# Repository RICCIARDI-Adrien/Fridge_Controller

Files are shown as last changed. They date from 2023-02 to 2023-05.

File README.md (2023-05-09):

# Fridge controller

A very simple controller with a light electronic BoM. It manages the fridge temperature with hardcoded thresholds and hysteresis.

## Project information

The board is powered by a PIC12F683 MCU. It samples the fridge or freezer temperature through a NTC sensor. It then controls the fridge cold unit through a 230V/12A relay.

### Hardware

The board schematic and PCB are designed with KiCad 6.

### Firmware

The microcontroller firmware is compiled with the free version of Microchip XC8 compiler.

## Photo gallery

Naked PCB :
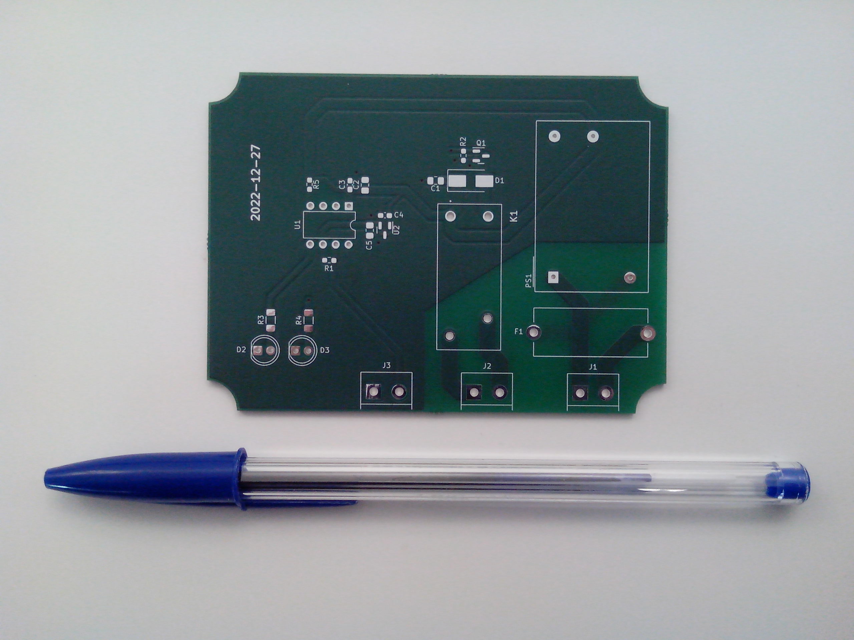
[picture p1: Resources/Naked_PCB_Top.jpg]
Naked PCB top

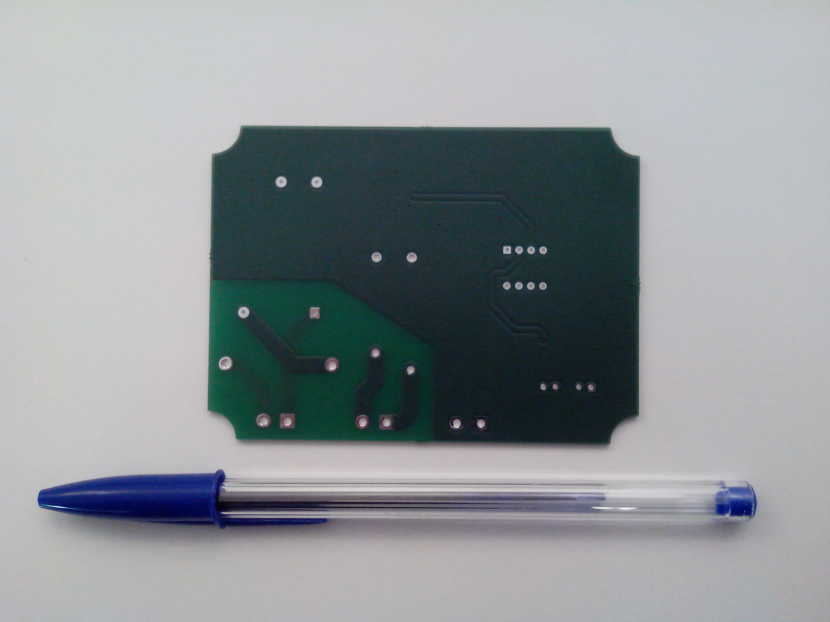
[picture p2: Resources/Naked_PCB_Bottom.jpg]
Naked PCB bottom


Assembled PCB :
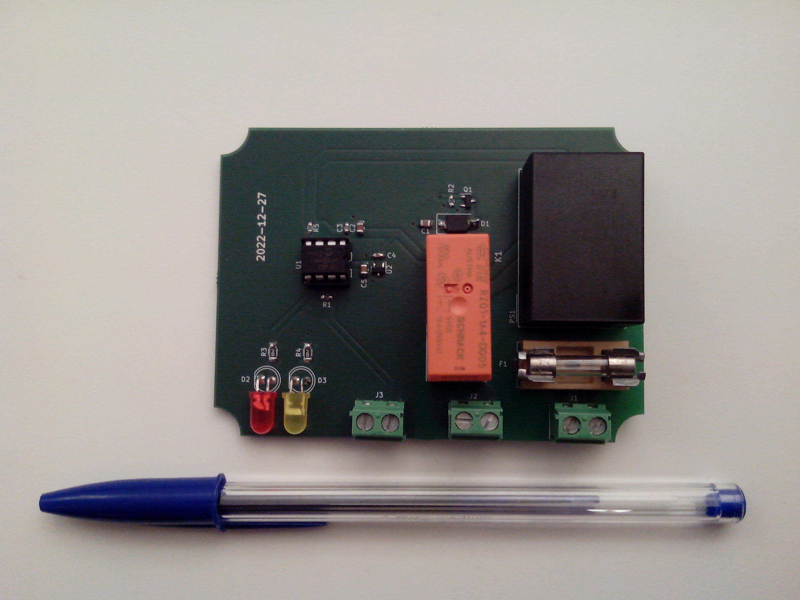
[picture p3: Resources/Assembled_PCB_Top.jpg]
Assembled PCB top

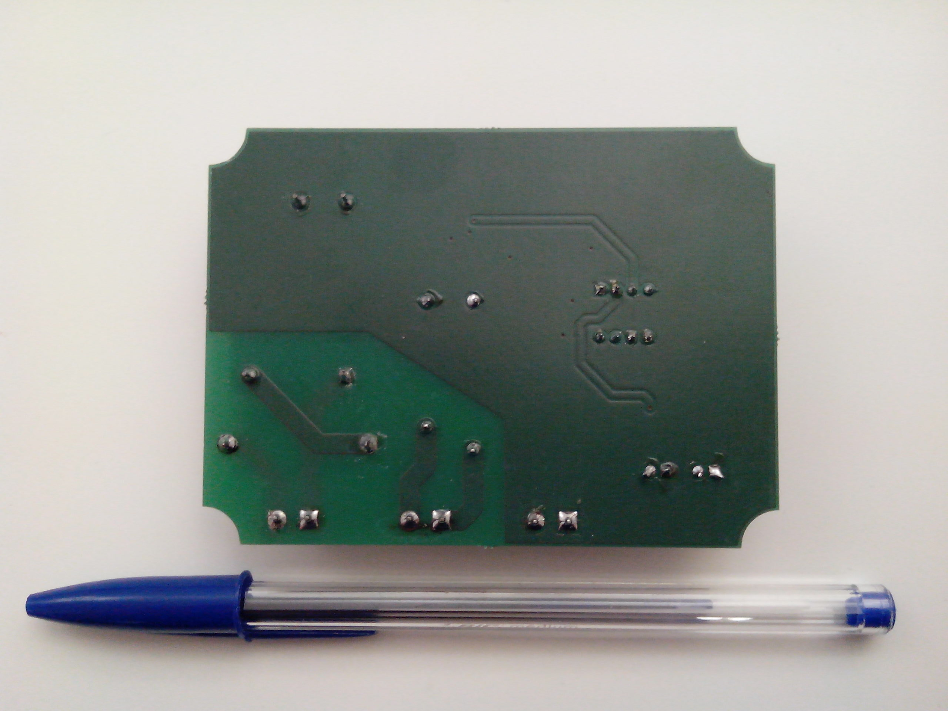
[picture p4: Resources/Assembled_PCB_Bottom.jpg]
Assembled PCB bottom


Connector adapters for the targeted freezer :
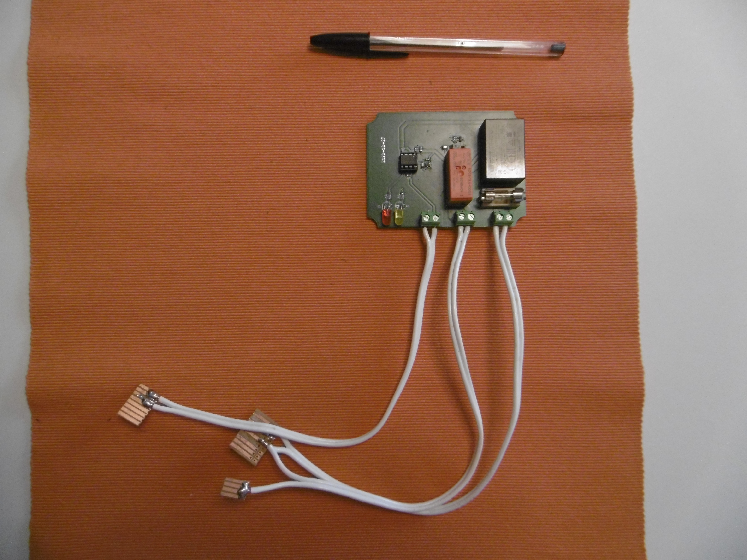
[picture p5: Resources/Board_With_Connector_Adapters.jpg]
Board with connector adapters


Transparent plastic casing (reference Deltron 479-0160-0) :
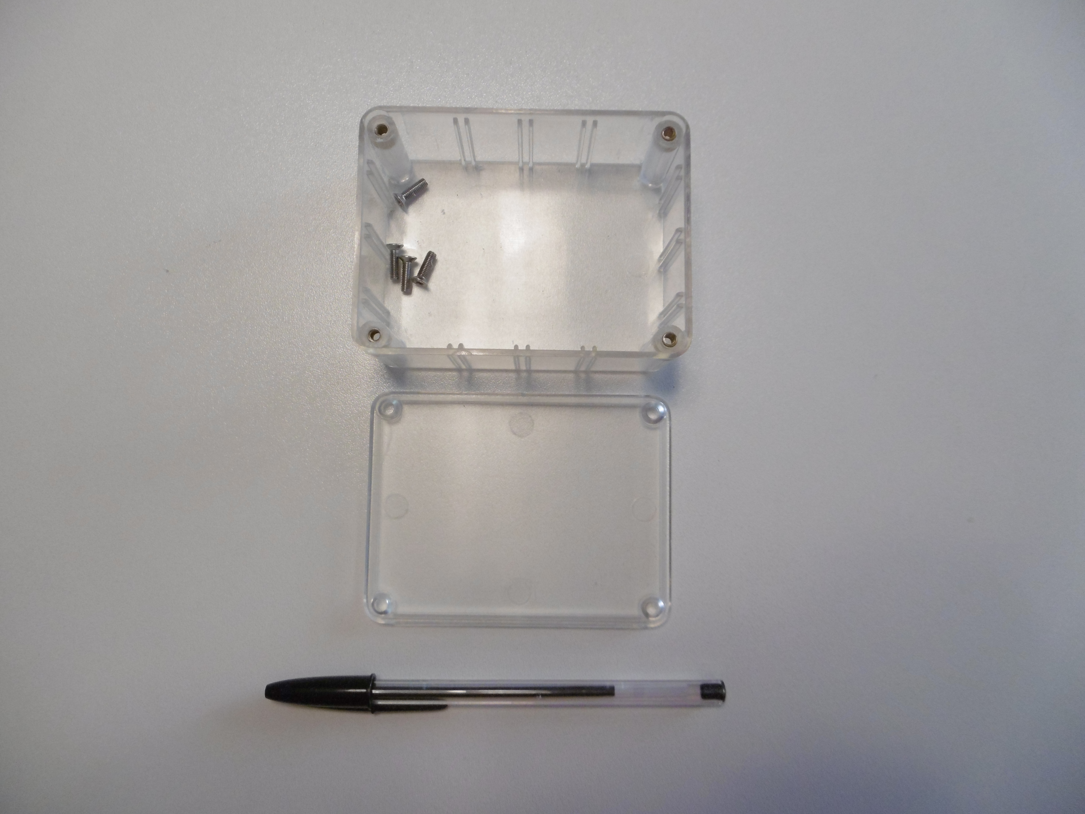
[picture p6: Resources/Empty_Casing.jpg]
Plastic casing


Board inside the casing with drilled holes and connector adapters :
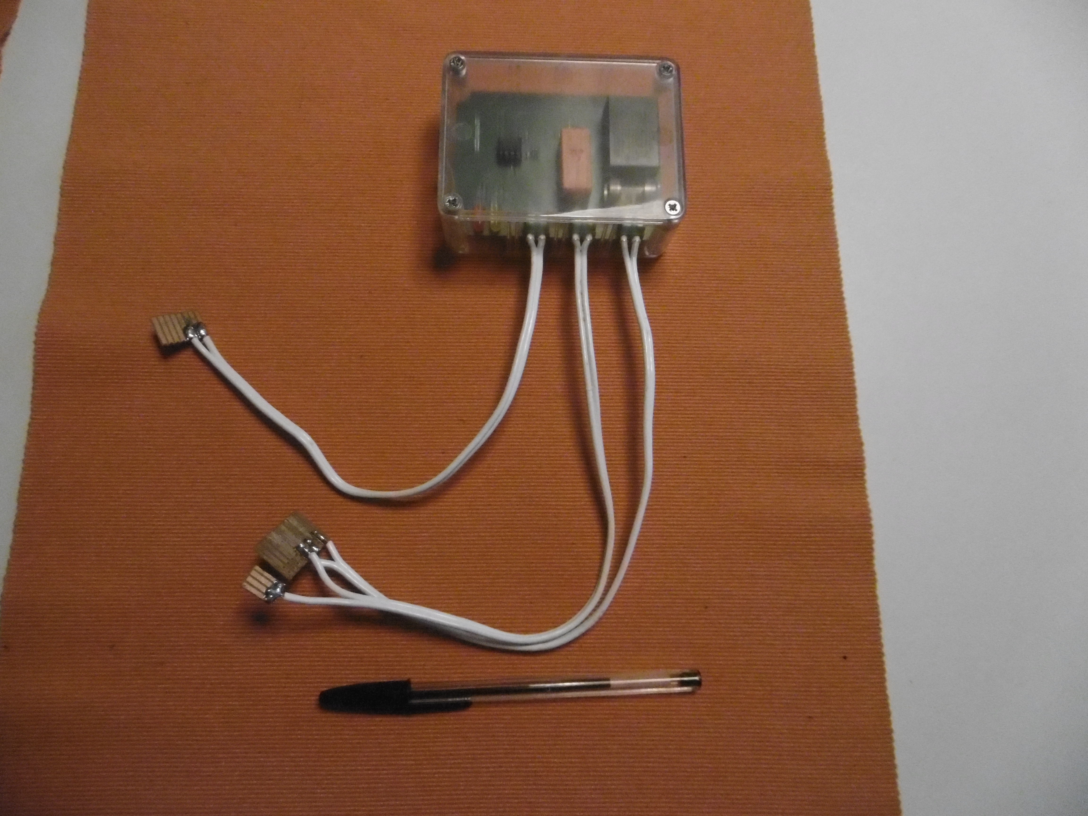
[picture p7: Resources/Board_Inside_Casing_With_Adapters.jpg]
Board inside casing with adapters


The board controlling the freezer in a basement :
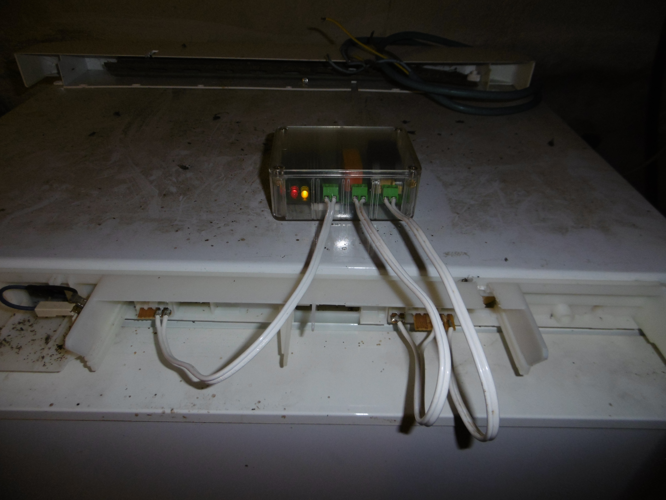
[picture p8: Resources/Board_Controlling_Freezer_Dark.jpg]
Board controlling freezer dark

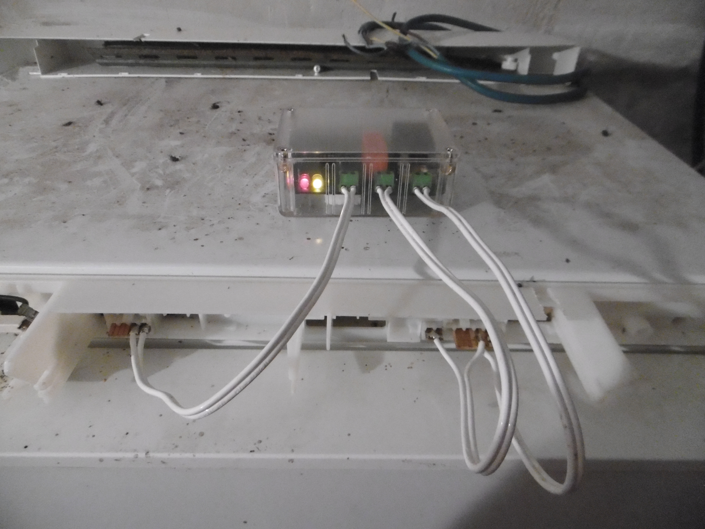
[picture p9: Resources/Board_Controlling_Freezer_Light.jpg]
Board controlling freezer light


## Technical information about the Brandt UD2321 freezer

The following information have been found through reverse engineering, so be careful about their accuracy !  

The picture below shows the connector names (the names are taken from the original controller board PCB).  
There were no indications on the PCB of the pin numbers, so I assigned them myself.
Brandt UD2321 connectors

Connector CN1 signals :
| Pin number | Description |
| --- | --- |
| 1 | Not connected |
| 2 | Not connected |
| 3 | Original controller GND |
| 4 | NTC (thermal sensor) |

Connector CN2 signals :
| Pin number | Description |
| --- | --- |
| 1 | Cold unit (note 1) |
| 2 | Cold unit (note 1) |
| 3 | Not connected |
| 4 | Not connected |
| 5 | Door switch (note 2) |
| 6 | 230V neutral |
| 7 | Door switch (note 3) |
| 8 | 230V live |

Notes :
1. Connect CN2 pins 1 and 2 to neutral to start the cold unit.
2. Door switch contact is normally closed.
3. CN2 pin 7 is connected the 230V live on the original controller board.

Connector CN3 is not populated.

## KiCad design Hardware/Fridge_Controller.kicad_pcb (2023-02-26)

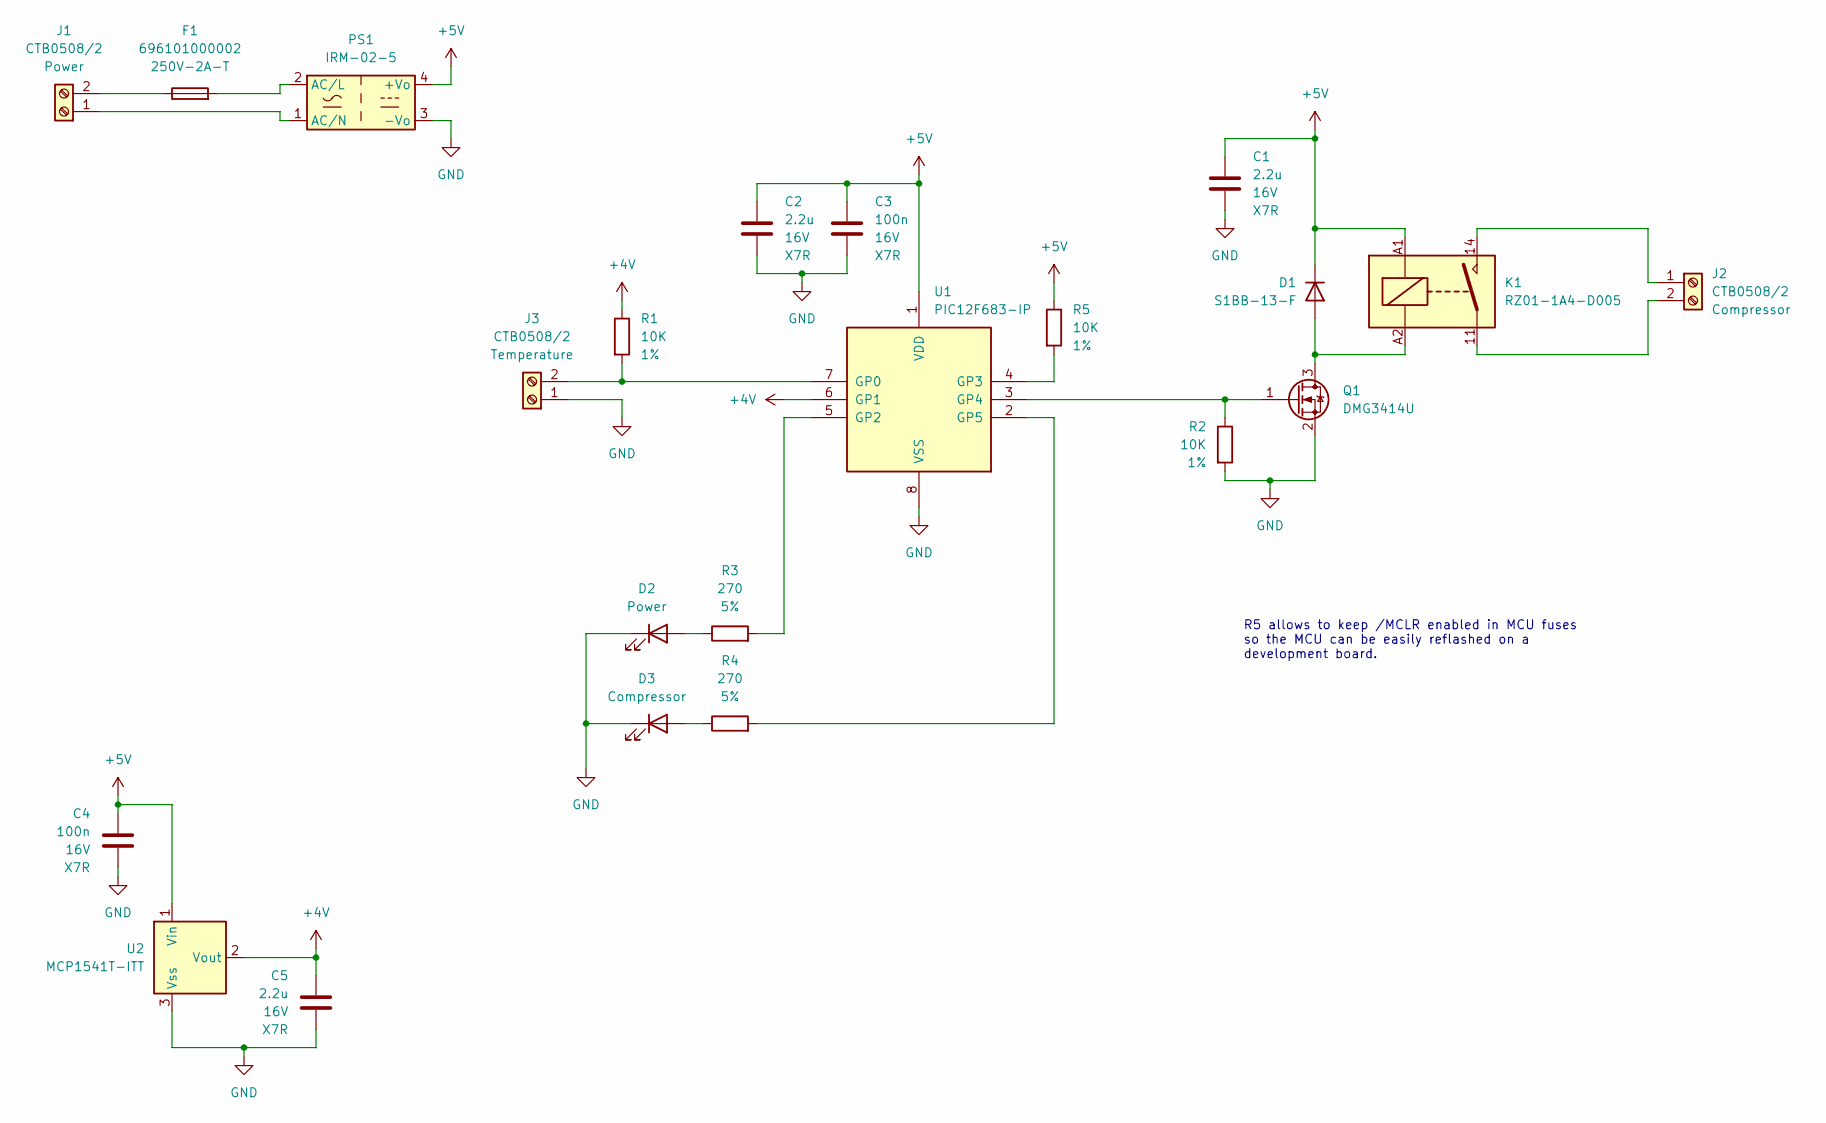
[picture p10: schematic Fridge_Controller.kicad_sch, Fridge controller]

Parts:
C1, C2, C5: 2.2u; C_0805_2012Metric_Pad1.18x1.45mm_HandSolder
C3, C4: 100n; C_0603_1608Metric_Pad1.08x0.95mm_HandSolder
D1: S1BB-13-F; D_SMB_Handsoldering
D2: Power; LED_D5.0mm
D3: Compressor; LED_D5.0mm
F1: 696101000002; Fuseholder_Cylinder-5x20mm_Stelvio-Kontek_PTF78_Horizontal_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
J1, J2, J3: CTB0508/2; TerminalBlock_bornier-2_P5.08mm
K1: RZ01-1A4-D005
PS1: IRM-02-5; Converter_ACDC_MeanWell_IRM-02-xx_THT
Q1: DMG3414U; SOT-23
R1, R2, R5: 10K; R_0603_1608Metric_Pad0.98x0.95mm_HandSolder
R3, R4: 270; R_1206_3216Metric_Pad1.30x1.75mm_HandSolder
U1: PIC12F683-IP; DIP-8_W7.62mm
U2: MCP1541T-ITT; SOT-23

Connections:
+4V: C5.1, R1.1, U1.6 (GP1), U2.2 (Vout)
+5V: C1.1, C2.1, C3.1, C4.1, D1.1 (K), K1.A1, PS1.4 (+Vo), R5.1, U1.1 (VDD), U2.1 (Vin)
GND: C1.2, C2.2, C3.2, C4.2, C5.2, D2.1 (K), D3.1 (K), J3.1, PS1.3 (-Vo), Q1.2 (S), R2.2, U1.8 (VSS), U2.3 (Vss)
unnamed: D1.2 (A), K1.A2, Q1.3 (D)
unnamed: D2.2 (A), R3.1
unnamed: D3.2 (A), R4.1
unnamed: F1.1, J1.2
unnamed: F1.2, PS1.2 (AC/L)
unnamed: J1.1, PS1.1 (AC/N)
unnamed: J2.1, K1.14
unnamed: J2.2, K1.11
unnamed: J3.2, R1.2, U1.7 (GP0)
unnamed: Q1.1 (G), R2.1, U1.3 (GP4)
unnamed: R3.2, U1.5 (GP2)
unnamed: R4.2, U1.2 (GP5)
unnamed: R5.2, U1.4 (GP3)

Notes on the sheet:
R5 allows to keep /MCLR enabled in MCU fuses so the MCU can be easily reflashed on a development board.

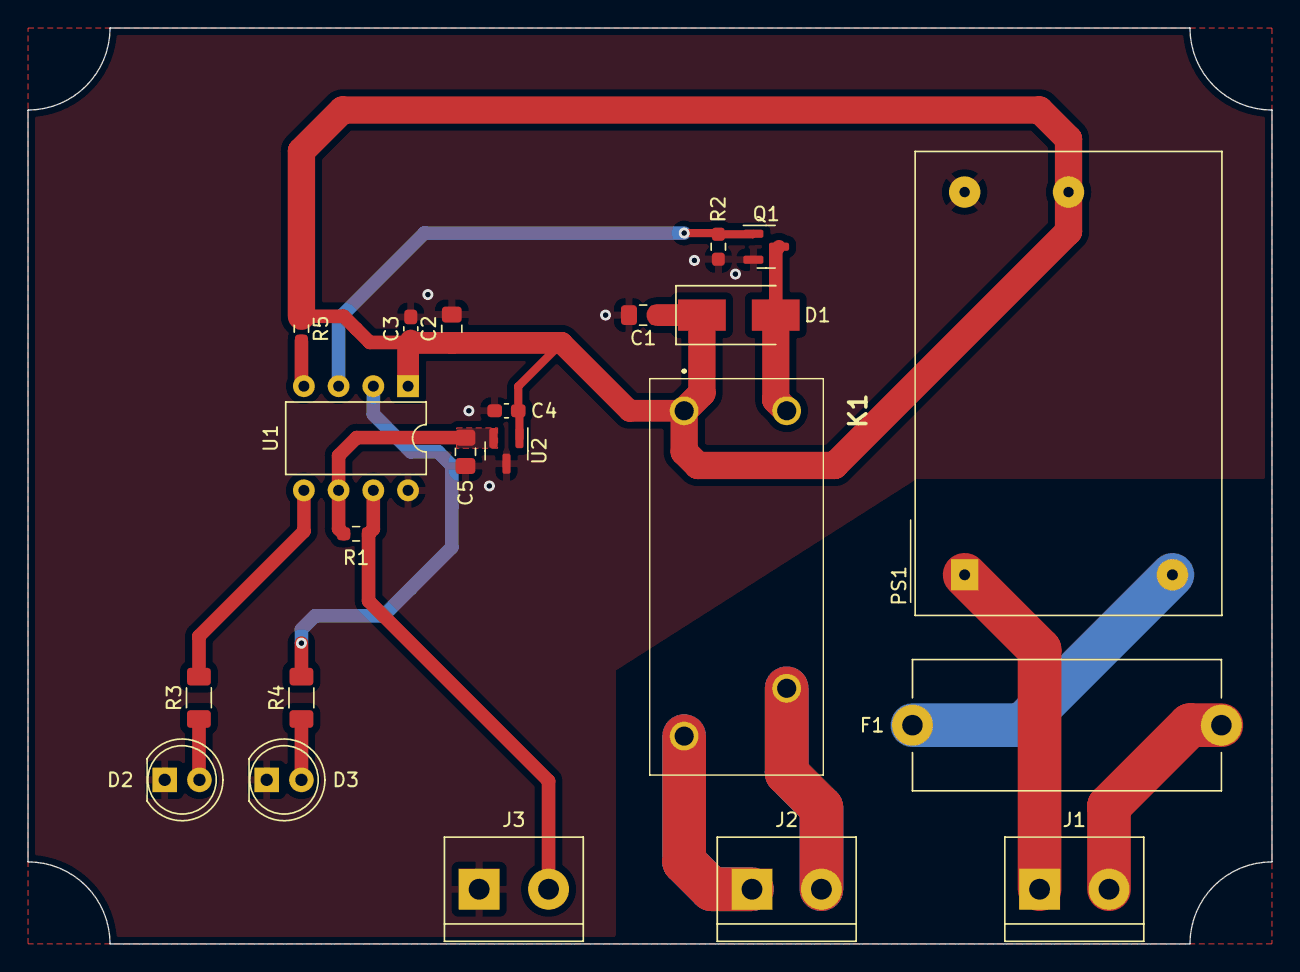
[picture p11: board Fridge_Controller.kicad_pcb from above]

Board: 2 copper layers, 91.0 x 67.0 mm, 22 parts (0 on the bottom side), 16 nets.

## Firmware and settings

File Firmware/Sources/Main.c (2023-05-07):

/** @file Main.c
 * Entry point and main loop of the fridge controller firmware.
 * @author Adrien RICCIARDI
 */
#include <ADC.h>
#include <xc.h>

//-------------------------------------------------------------------------------------------------
// Microcontroller configuration
//-------------------------------------------------------------------------------------------------
// CONFIG register
#pragma config FCMEN = OFF, IESO = OFF, BOREN = ON, CPD = OFF, CP = OFF, MCLRE = ON, PWRTE = ON, WDTE = OFF, FOSC = INTOSCIO // Disable Fail-Safe Clock Monitor, disable Internal External clock Switchover, enable Brown Out Detection, disable Data Code Protection, disable Code Protection, enable MCLR pin, enable Power-up Timer, disable Watchdog Timer, select the internal oscillator and keep the oscillator pins as GPIOs

//-------------------------------------------------------------------------------------------------
// Private constants
//-------------------------------------------------------------------------------------------------
/** The thermistor voltage divider voltage in millivolts. */
#define MAIN_THERMISTOR_VOLTAGE_DIVIDER_VOLTAGE_MILLIVOLTS 4096UL
/** The thermistor voltage divider R1 value in ohms. */
#define MAIN_THERMISTOR_VOLTAGE_DIVIDER_FIXED_RESISTOR_OHMS 10000UL

/** How many samples to get to compute the average on. */
#define MAIN_THERMISTOR_VOLTAGE_SAMPLES_COUNT 4 // Make sure the unsigned short value can't overflow with the sum of all samples when changing this value

/** The resistance corresponding to the highest temperature threshold, when reached the compressor is started. */
#define MAIN_THERMISTOR_THRESHOLD_HIGHEST_TEMPERATURE_RESISTANCE_OHMS 33160 // Stands for -19°C on the Brandt UD2321 freezer
/** The resistance corresponding to the lowest temperature threshold, when reached the compressor is stopped. */
#define MAIN_THERMISTOR_THRESHOLD_LOWEST_TEMPERATURE_RESISTANCE_OHMS 45000 // Stands for -26°C on the Brandt UD2321 freezer

/** The GPIO pin that drives the power led. */
#define MAIN_PIN_SET_POWER_LED(Value) GPIObits.GP2 = Value
/** The GPIO pin that drives the compressor led. */
#define MAIN_PIN_SET_COMPRESSOR_LED(Value) GPIObits.GP5 = Value
/** The GPIO pin that drives the compressor relay. */
#define MAIN_PIN_SET_COMPRESSOR_RELAY(Value) GPIObits.GP4 = Value

//-------------------------------------------------------------------------------------------------
// Private functions
//-------------------------------------------------------------------------------------------------
/** Compute the fridge thermistor resistance.
 * @param Sampled_Voltage The thermistor voltage in range [0; 1023].
 * @return The thermistor resistance in ohms.
 */
static inline unsigned long MainComputeThermistorResistance(unsigned short Sampled_Voltage)
{
	unsigned long Voltage_Millivolts, Thermistor_Resistance;

	// Convert the sampled voltage to millivolts
	Voltage_Millivolts = (MAIN_THERMISTOR_VOLTAGE_DIVIDER_VOLTAGE_MILLIVOLTS * Sampled_Voltage) / 1023UL; // The maximum sampled value (1023) is equal to the voltage divider voltage, the maximum value for the multiplication is 4000*1023 and can't overflow an unsigned 32-bit integer

	// Retrieve the R2 value of the voltage divider bridge with the following formula : R2 = (U2 * R1) / (U - U2)
	Thermistor_Resistance = Voltage_Millivolts * MAIN_THERMISTOR_VOLTAGE_DIVIDER_FIXED_RESISTOR_OHMS; // The maximum value for the multiplication is 4000*10000 and can't overflow an unsigned 32-bit integer
	if (Voltage_Millivolts >= MAIN_THERMISTOR_VOLTAGE_DIVIDER_VOLTAGE_MILLIVOLTS) Voltage_Millivolts = MAIN_THERMISTOR_VOLTAGE_DIVIDER_VOLTAGE_MILLIVOLTS - 1; // Handle negative values (even if they should not occur) and division by zero
	Thermistor_Resistance /= MAIN_THERMISTOR_VOLTAGE_DIVIDER_VOLTAGE_MILLIVOLTS - Voltage_Millivolts;

	return Thermistor_Resistance;
}

//-------------------------------------------------------------------------------------------------
// Entry point
//-------------------------------------------------------------------------------------------------
void main(void)
{
	unsigned short Thermistor_Voltage_Mean;
	unsigned char i;
	unsigned long Thermistor_Resistance;

	// Clock the chip from the internal oscillator at 1MHz
	OSCCON = 0x41;
	while (!OSCCONbits.HTS); // Wait for the clock to be stable, even if it already should be

	// Configure modules
	ADCInitialize();

	// Configure the pins now that all modules are initialized
	CMCON0 = 0x07; // Disable the comparator analog mode on all pins as comparator is not used
	// Configure GP0 and GP1 as analog inputs and other pins as digital
	ANSEL &= 0xF0;
	ANSEL |= 0x03;
	// Make sure leds and relay will be off
	MAIN_PIN_SET_POWER_LED(0);
	MAIN_PIN_SET_COMPRESSOR_LED(0);
	MAIN_PIN_SET_COMPRESSOR_RELAY(0);
	// Configure leds and relay pins as output
	TRISIO &= 0xCB;

	// Everything is initialized, turn on power led
	MAIN_PIN_SET_POWER_LED(1);
	// Blink compressor led 3 times to tell that everything is OK
	for (i = 0; i < 3; i++)
	{
		MAIN_PIN_SET_COMPRESSOR_LED(1);
		__delay_ms(250);
		MAIN_PIN_SET_COMPRESSOR_LED(0);
		__delay_ms(250);
	}

	// Main loop
	while (1)
	{
		// Get all samples with a little delay between each sample
		Thermistor_Voltage_Mean = 0;
		for (i = 0; i < MAIN_THERMISTOR_VOLTAGE_SAMPLES_COUNT; i++)
		{
			Thermistor_Voltage_Mean += ADCSampleFridgeTemperatureVoltage();
			__delay_ms(1000);
		}
		// Compute the moving average
		Thermistor_Voltage_Mean /= MAIN_THERMISTOR_VOLTAGE_SAMPLES_COUNT;

		// Use simple thresholds with hysteresis to drive the compressor
		Thermistor_Resistance = MainComputeThermistorResistance(Thermistor_Voltage_Mean);
		// The thermistor is a CTN on the UD2321, so resistance decreases when temperature increases
		if (Thermistor_Resistance <= MAIN_THERMISTOR_THRESHOLD_HIGHEST_TEMPERATURE_RESISTANCE_OHMS)
		{
			MAIN_PIN_SET_COMPRESSOR_RELAY(1);
			MAIN_PIN_SET_COMPRESSOR_LED(1);
		}
		else if (Thermistor_Resistance >= MAIN_THERMISTOR_THRESHOLD_LOWEST_TEMPERATURE_RESISTANCE_OHMS)
		{
			MAIN_PIN_SET_COMPRESSOR_RELAY(0);
			MAIN_PIN_SET_COMPRESSOR_LED(0);
		}
	}
}

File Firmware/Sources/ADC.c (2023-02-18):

/** @file ADC.c
 * See ADC.h for description.
 * @author Adrien RICCIARDI
 */
#include <ADC.h>
#include <xc.h>

//-------------------------------------------------------------------------------------------------
// Public functions
//-------------------------------------------------------------------------------------------------
void ADCInitialize(void)
{
	// Set the ADC conversion clock to Fosc/4, it allows to complete a conversion in 4us with Fosc = 1MHz (this is slow enough to reach a correct ADC setup time and fast enough in this application)
	ANSEL &= 0x0F;
	ANSEL |= 0x40;

	// Configure the ADC module
	ADCON0 = 0xC1; // Enable right justification of the sampling result, use VREF pin as reference voltage, select channel 0 and enable the ADC module
}

unsigned short ADCSampleFridgeTemperatureVoltage(void)
{
	unsigned short Result;

	// Start conversion
	ADCON0bits.GO = 1;

	// Wait for the conversion to terminate
	while (ADCON0bits.GO);

	// Retrieve the sampled voltage
	Result = (ADRESH << 8) | ADRESL;
	Result &= 0x03FF; // Bits 15 to 10 are undefined, so force them to zero

	return Result;
}

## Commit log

2022-12-26 Initial commit. Added an empty KiCad project.
    [Fridge_Controller.kicad_pcb, Fridge_Controller.kicad_sch]
2022-12-27 [Hardware] Added RZ01-1A4-D005 relay symbol, footprint and 3D model.
2022-12-27 [Hardware] Added schematic.
    [Fridge_Controller.kicad_sch]
2023-01-14 [Hardware] Added fuse, fuse holder and screw terminals part references to schematics.
    [Fridge_Controller.kicad_sch]
2023-02-02 [Hardware] Added a pull-up resistor on microcontroller /MCLR pin so the /MCLR signal can be left active in the MCU fuses and the MCU can be more easily reflashed when inserted on a development board.
    [Fridge_Controller.kicad_sch]
2023-02-02 [Firmware] Started firmware implementation. Added microcontroller fuses configuration.
2023-02-18 [Firmware] Switched microcontroller clock speed to 1MHz and added blinking led test.
2023-02-18 [Firmware] Added GPIOs configuration, ADC module implementation and related test.
2023-02-20 [Firmware] Added the conversion to a resistance of the sampled thermistor voltage.
2023-02-20 [Firmware] Added output pins control (leds and relay).
2023-02-26 [Hardware] Added PCB edges.
    [Fridge_Controller.kicad_pcb]
2023-02-26 [Hardware] Placed components on the PCB, added the logic ground planes and the keepout areas for the mains voltage.
    [Fridge_Controller.kicad_pcb]
2023-02-26 [Hardware] Routed all PCB tracks.
    [Fridge_Controller.kicad_pcb]
2023-02-26 [Hardware] Cleaned all PCB warnings.
    [Fridge_Controller.kicad_pcb]
2023-04-11 Added PCB photos to README.md.
2023-05-07 [Firmware] Adjusted the precision of the thermal sensor voltage divider value.
2023-05-09 Added pictures of the project assembly and the running board to the README.md.
